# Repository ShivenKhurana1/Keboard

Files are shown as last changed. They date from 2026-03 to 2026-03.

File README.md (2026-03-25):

# Keboard

A custom 60% mechanical keyboard featuring an OLED display and rotary encoder for enhanced functionality. coded using [onshape](https://cad.onshape.com/documents/cca7080cfaf346b1d03e6a45/w/840138e854193d740b07961a/e/62251870f6a2fd42355be13b)

## Features

- **60% Layout**: Compact 60-key layout without function row, navigation cluster, or numpad
- **OLED Display**: 0.91" I2C OLED for displaying status, layers, or custom animations
- **Rotary Encoder**: EC11 rotary encoder for volume control, scrolling, or custom functions
- **Hot-Swap Sockets**: Kailh hot-swap sockets for easy switch swapping without soldering
- **RP2040 Controller**: Powered by Raspberry Pi Pico for excellent performance and QMK compatibility

## Gallery

### CAD Design
CAD Design

### Schematics
Schematics

### PCB Design
PCB

## Bill of Materials

|Item |Qty  |Link |Price |Running total|
|---|-----|---|---|---|
|Keycaps |1 set|[Aliexpress](https://www.aliexpress.us/item/3256809438061445.html?gatewayAdapt=glo2usa4itemAdapt) |13$ |13$ |
|Switches |90pc |[Akko V3 Creamy Purple Pro Switch](https://en.akkogear.com/product/akko-v3-creamy-purple-pro-switch/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) |$30.25|43$ |
|OLED |1 |[0.91 Inch OLED Display](https://www.aliexpress.us/item/3256808609571956.html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) |$5.55 |49$ |
|Raspberry Pi Pico |1 |[Digikey](https://www.digikey.com/en/products/detail/raspberry-pi/SC0917/16608257) |$5.00 |54$ |
|EC11 rotary encoder |1 |[aliexpress](https://www.aliexpress.us/item/3256801690870145.html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) |$2.60 |56$ |
|PCB |1 |JLCPCB |$25.61|82$ |
|Hotswap sockets |70 |[Aliexpress](https://www.aliexpress.us/item/3256807039037559.html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) |$9.54 |92$ |
|Stabilizer Set |1 |[Aliexpress](https://www.aliexpress.us/item/3256801817127792.html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) |$4.25 |96$ |
|Diodes |100  |[aliexpress](https://www.aliexpress.com/ssr/300001493/welcomegiftspmpc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..)|$4.77 |101$ |
|Coupon (3$ off 15$ Aliexpress)| | |-3 |98$ |

**Total Estimated Cost: ~$100**

### PCB Pricing Example
JLCPCB Pricing

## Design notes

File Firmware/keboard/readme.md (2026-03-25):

# keboard

QMK firmware for the keboard RP2040 (Raspberry Pi Pico) keyboard.

## Pins

- Rows: GP14, GP15, GP16, GP17, GP18
- Cols: GP0..GP13
- Encoder: GP27 (A), GP26 (B)
- OLED I2C: GP20 (SDA), GP21 (SCL)

## Notes

- `DIODE_DIRECTION` is set to `COL2ROW`. If your matrix is reversed, flip it in config.h.
- The layout is a generic 5x14 grid. Adjust the keymap to match your physical layout.

## Build

Copy this folder into `qmk_firmware/keyboards/clear60`, then run:

```
qmk compile -kb clear60 -km default
```

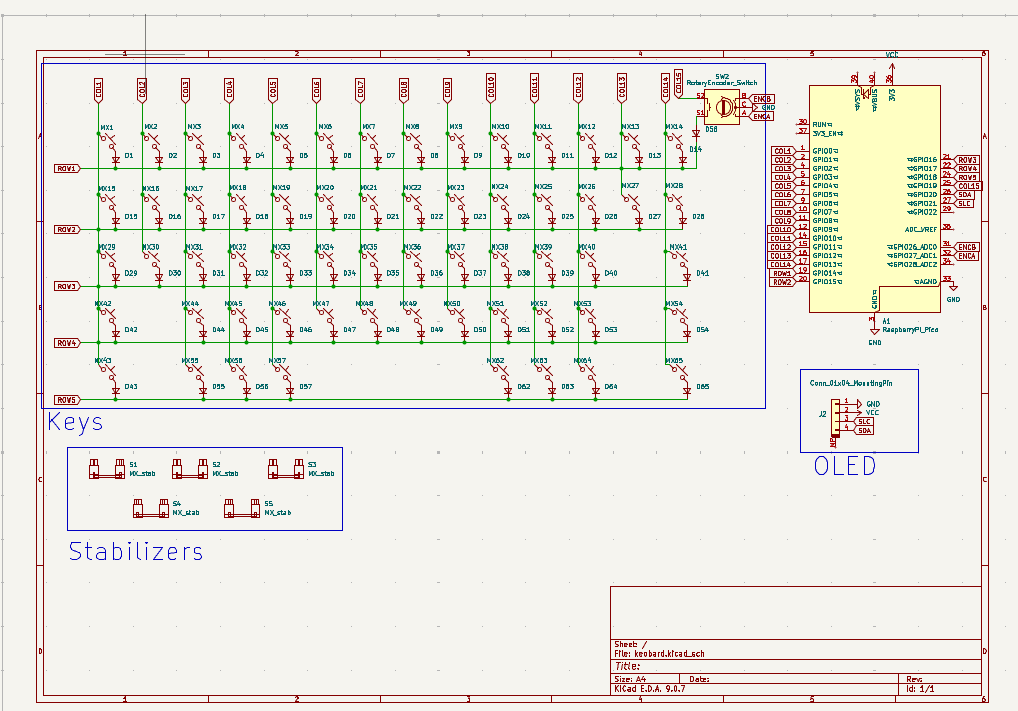
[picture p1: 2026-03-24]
assets/schematics.png

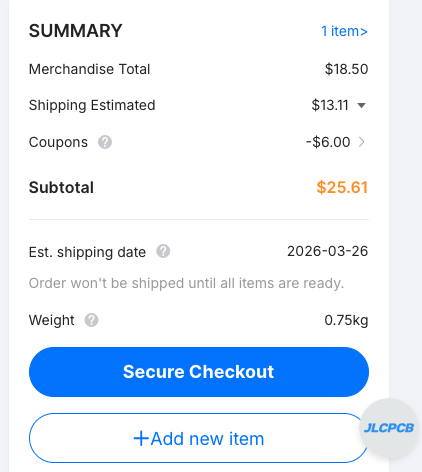
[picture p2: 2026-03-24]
assets/jlcpcb.png

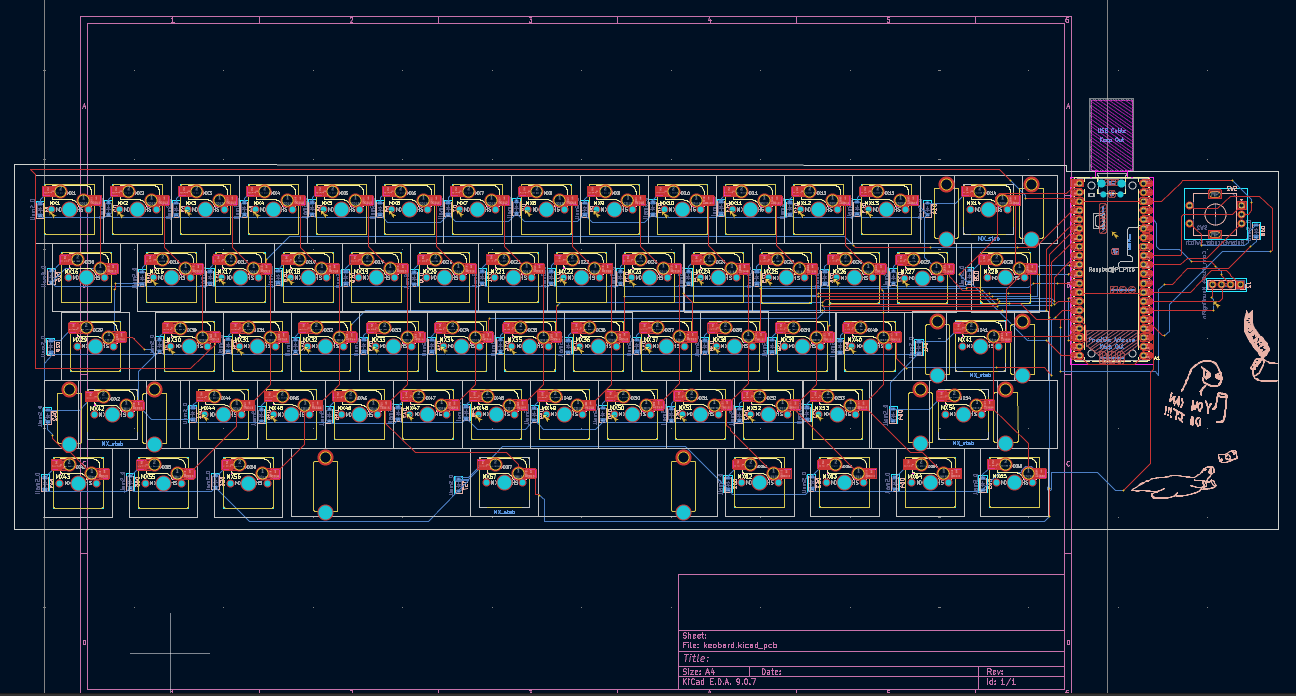
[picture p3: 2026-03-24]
assets/pcb.png

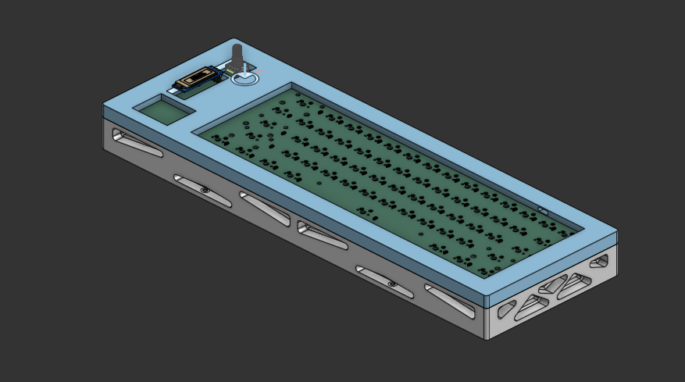
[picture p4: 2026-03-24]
assets/cad.png

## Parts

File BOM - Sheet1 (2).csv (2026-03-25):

Item | Qty | Link | Price | Running total
Keycaps | 1 set | [Aliexpress](https://www.aliexpress.us/item/3256809438061445.html?gatewayAdapt=glo2usa4itemAdapt) | 13$ | 13$
Switches | 90pc | [Akko V3 Creamy Purple Pro Switch](https://en.akkogear.com/product/akko-v3-creamy-purple-pro-switch/?attribute_quantity=45+pcs&wmc-currency=USD | $30.25 | 43$
OLED | 1 | [0.91 Inch OLED Display](https://www.aliexpress.us/item/3256808609571956.html?curPageLogUid=osvBYXtlXRIq | $5.55 | 49$
Raspberry Pi Pico | 1 | [Digikey](https://www.digikey.com/en/products/detail/raspberry-pi/SC0917/16608257) | $5.00 | 54$
EC11 rotary encoder | 1 | [aliexpress](https://www.aliexpress.us/item/3256801690870145.html | $2.60 | 56$
PCB | 1 | JLCPCB | $25.61 | 82$
Hotswap sockets | 70 | [Aliexpress](https://www.aliexpress.us/item/3256807039037559.html?src=google | $9.54 | 92$
Stabilizer Set | 1 | [Aliexpress](https://www.aliexpress.us/item/3256801817127792.html?curPageLogUid=1E7nWo6FwrMm | $4.25 | 96$
Diodes | 100 | [aliexpress](https://www.aliexpress.com/ssr/300001493/welcomegiftspmpc?businessCode=ug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 | $4.77 | 101$
Coupon (3$ off 15$ Aliexpress) |  |  | -3 | 98$

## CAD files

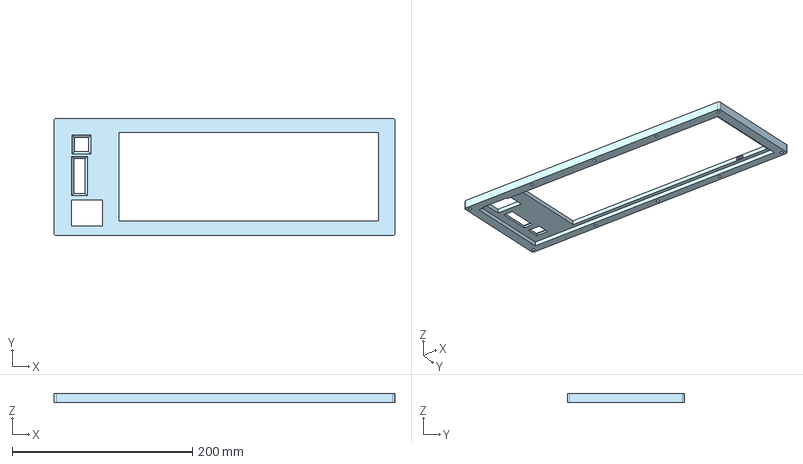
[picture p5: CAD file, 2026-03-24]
CAD/Top Case (2).step
378.7 x 130.5 x 10.2 mm

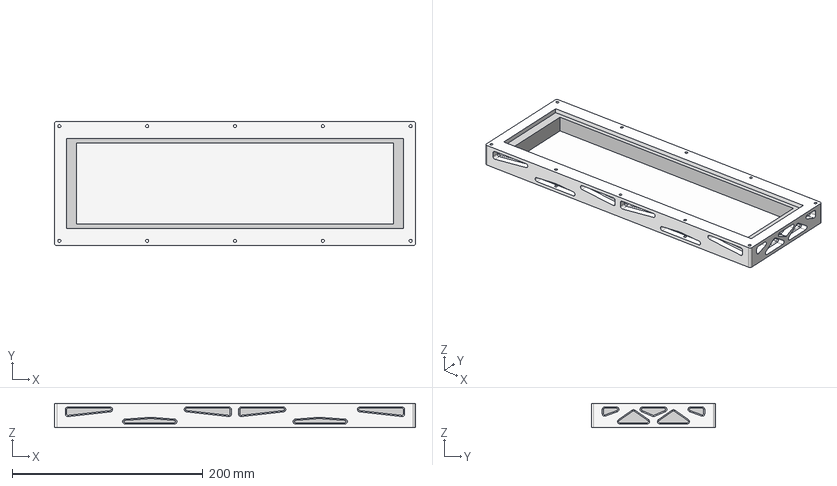
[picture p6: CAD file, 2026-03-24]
CAD/Case.step
378.7 x 130.5 x 25.4 mm

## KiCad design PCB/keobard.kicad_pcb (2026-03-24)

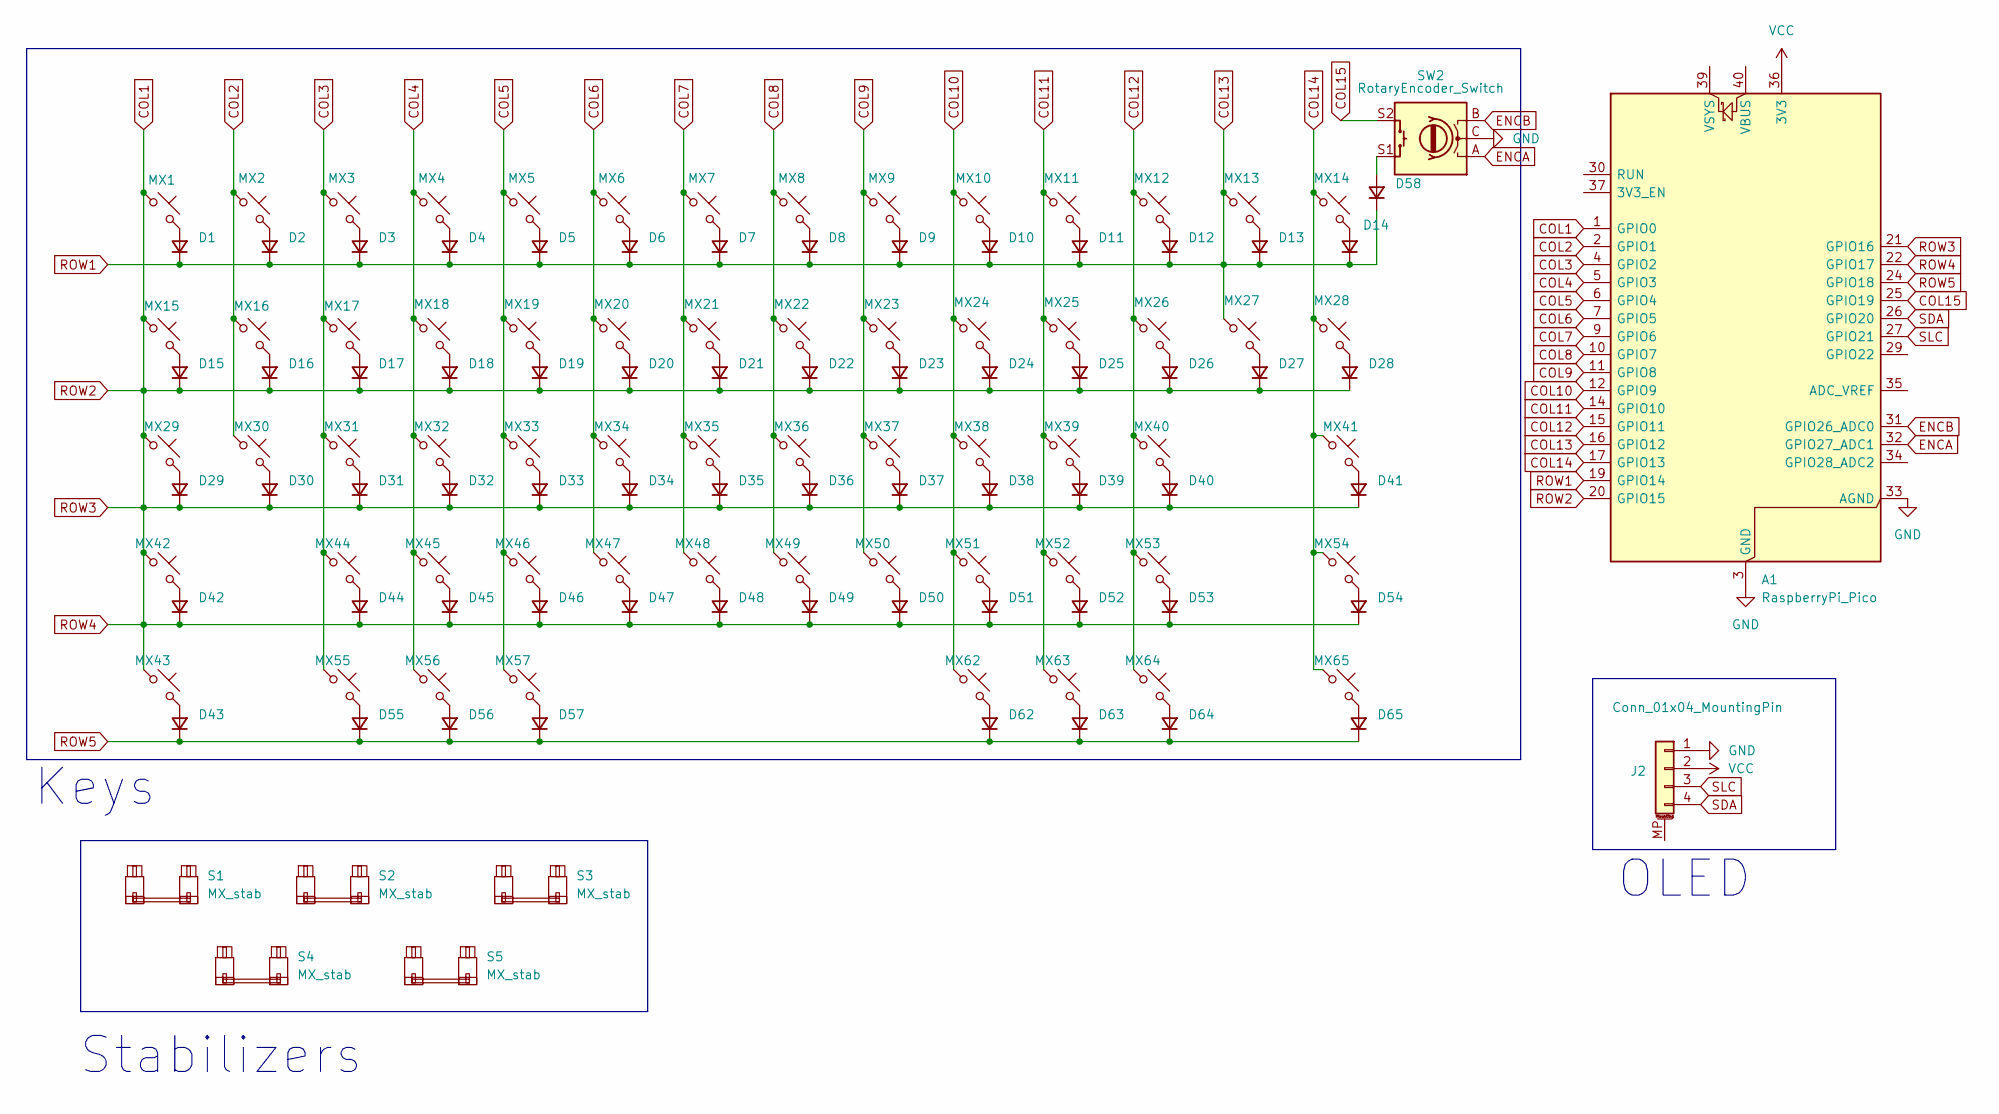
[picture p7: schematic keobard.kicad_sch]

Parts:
A1: RaspberryPi_Pico; RaspberryPi_Pico_Common_Unspecified
D1, D2, D3, D4, D5, D6, D7, D8, D9, D10, D11, D12, D13, D14, D15, D16, D17, D18, D19, D20, D21, D22, D23, D24, D25, D26, D27, D28, D29, D30, D31, D32, D33, D34, D35, D36, D37, D38, D39, D40, D41, D42, D43, D44, D45, D46, D47, D48, D49, D50, D51, D52, D53, D54, D55, D56, D57, D58, D62, D63, D64, D65: D_Small; D_SOD-123
J2: Conn_01x04_MountingPin; PinHeader_1x04_P2.54mm_Vertical
MX1, MX2, MX3, MX4, MX5, MX6, MX7, MX8, MX9, MX10, MX11, MX12, MX13, MX14, MX15, MX16, MX17, MX18, MX19, MX20, MX21, MX22, MX23, MX24, MX25, MX26, MX27, MX28, MX29, MX30, MX31, MX32, MX33, MX34, MX35, MX36, MX37, MX38, MX39, MX40, MX41, MX42, MX43, MX44, MX45, MX46, MX47, MX48, MX49, MX50, MX51, MX52, MX53, MX54, MX55, MX56, MX57, MX62, MX63, MX64, MX65: MX_SW_HS; SW_MX_HS_CPG151101S11_1u
S1, S2, S3: MX_stab; STAB_MX_P_2u
S4: MX_stab; STAB_MX_P_2.75u
S5: MX_stab; STAB_MX_P_6.25u
SW2: RotaryEncoder_Switch; RotaryEncoder_Alps_EC11E-Switch_Vertical_H20mm

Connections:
COL1: A1.1 (GPIO0), A1.20 (GPIO15), A1.21 (GPIO16), A1.22 (GPIO17), D15.1 (K), D16.1 (K), D17.1 (K), D18.1 (K), D19.1 (K), D20.1 (K), D21.1 (K), D22.1 (K), D23.1 (K), D24.1 (K), D25.1 (K), D26.1 (K), D27.1 (K), D28.1 (K), D29.1 (K), D30.1 (K), D31.1 (K), D32.1 (K), D33.1 (K), D34.1 (K), D35.1 (K), D36.1 (K), D37.1 (K), D38.1 (K), D39.1 (K), D40.1 (K), D41.1 (K), D42.1 (K), D44.1 (K), D45.1 (K), D46.1 (K), D47.1 (K), D48.1 (K), D49.1 (K), D50.1 (K), D51.1 (K), D52.1 (K), D53.1 (K), D54.1 (K), MX1.1, MX15.1, MX29.1, MX42.1, MX43.1
COL2: A1.2 (GPIO1), MX2.1, MX16.1, MX30.1
COL3: A1.4 (GPIO2), MX3.1, MX17.1, MX31.1, MX44.1, MX55.1
COL4: A1.5 (GPIO3), MX4.1, MX18.1, MX32.1, MX45.1, MX56.1
COL5: A1.6 (GPIO4), MX5.1, MX19.1, MX33.1, MX46.1, MX57.1
COL6: A1.7 (GPIO5), MX6.1, MX20.1, MX34.1, MX47.1
COL7: A1.9 (GPIO6), MX7.1, MX21.1, MX35.1, MX48.1
COL8: A1.10 (GPIO7), MX8.1, MX22.1, MX36.1, MX49.1
COL9: A1.11 (GPIO8), MX9.1, MX23.1, MX37.1, MX50.1
COL10: A1.12 (GPIO9), MX10.1, MX24.1, MX38.1, MX51.1, MX62.1
COL11: A1.14 (GPIO10), MX11.1, MX25.1, MX39.1, MX52.1, MX63.1
COL12: A1.15 (GPIO11), MX12.1, MX26.1, MX40.1, MX53.1, MX64.1
COL13: A1.16 (GPIO12), A1.19 (GPIO14), D1.1 (K), D2.1 (K), D3.1 (K), D4.1 (K), D5.1 (K), D6.1 (K), D7.1 (K), D8.1 (K), D9.1 (K), D10.1 (K), D11.1 (K), D12.1 (K), D13.1 (K), D14.1 (K), D58.1 (K), MX13.1, MX27.1
COL14: A1.17 (GPIO13), MX14.1, MX28.1, MX41.1, MX54.1, MX65.1
COL15: A1.25 (GPIO19), SW2.S2
ENCA: A1.32 (GPIO27_ADC1), SW2.A
ENCB: A1.31 (GPIO26_ADC0), SW2.B
GND: A1.3 (GND), A1.8 (GND), A1.13 (GND), A1.18 (GND), A1.23 (GND), A1.28 (GND), A1.33 (AGND), A1.38 (GND), J2.1, SW2.C
unnamed: D1.2 (A), MX1.2
unnamed: D2.2 (A), MX2.2
unnamed: D3.2 (A), MX3.2
unnamed: D4.2 (A), MX4.2
unnamed: D5.2 (A), MX5.2
unnamed: D6.2 (A), MX6.2
unnamed: D7.2 (A), MX7.2
unnamed: D8.2 (A), MX8.2
unnamed: D9.2 (A), MX9.2
unnamed: D10.2 (A), MX10.2
unnamed: D11.2 (A), MX11.2
unnamed: D12.2 (A), MX12.2
unnamed: D13.2 (A), MX13.2
unnamed: D14.2 (A), MX14.2
unnamed: D15.2 (A), MX15.2
unnamed: D16.2 (A), MX16.2
unnamed: D17.2 (A), MX17.2
unnamed: D18.2 (A), MX18.2
unnamed: D19.2 (A), MX19.2
unnamed: D20.2 (A), MX20.2
unnamed: D21.2 (A), MX21.2
unnamed: D22.2 (A), MX22.2
unnamed: D23.2 (A), MX23.2
unnamed: D24.2 (A), MX24.2
unnamed: D25.2 (A), MX25.2
unnamed: D26.2 (A), MX26.2
unnamed: D27.2 (A), MX27.2
unnamed: D28.2 (A), MX28.2
unnamed: D29.2 (A), MX29.2
unnamed: D30.2 (A), MX30.2
unnamed: D31.2 (A), MX31.2
unnamed: D32.2 (A), MX32.2
unnamed: D33.2 (A), MX33.2
unnamed: D34.2 (A), MX34.2
unnamed: D35.2 (A), MX35.2
unnamed: D36.2 (A), MX36.2
unnamed: D37.2 (A), MX37.2
unnamed: D38.2 (A), MX38.2
unnamed: D39.2 (A), MX39.2
unnamed: D40.2 (A), MX40.2
unnamed: D41.2 (A), MX41.2
unnamed: D42.2 (A), MX42.2
unnamed: D43.2 (A), MX43.2
unnamed: D44.2 (A), MX44.2
unnamed: D45.2 (A), MX45.2
unnamed: D46.2 (A), MX46.2
unnamed: D47.2 (A), MX47.2
unnamed: D48.2 (A), MX48.2
unnamed: D49.2 (A), MX49.2
unnamed: D50.2 (A), MX50.2
unnamed: D51.2 (A), MX51.2
unnamed: D52.2 (A), MX52.2
unnamed: D53.2 (A), MX53.2
unnamed: D54.2 (A), MX54.2
unnamed: D55.2 (A), MX55.2
unnamed: D56.2 (A), MX56.2
unnamed: D57.2 (A), MX57.2
unnamed: D58.2 (A), SW2.S1
unnamed: D62.2 (A), MX62.2
unnamed: D63.2 (A), MX63.2
unnamed: D64.2 (A), MX64.2
unnamed: D65.2 (A), MX65.2
ROW5: A1.24 (GPIO18), D43.1 (K), D55.1 (K), D56.1 (K), D57.1 (K), D62.1 (K), D63.1 (K), D64.1 (K), D65.1 (K)
SDA: A1.26 (GPIO20), J2.4
SLC: A1.27 (GPIO21), J2.3
VCC: A1.36 (3V3), J2.2

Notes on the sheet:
Keys
OLED
Stabilizers

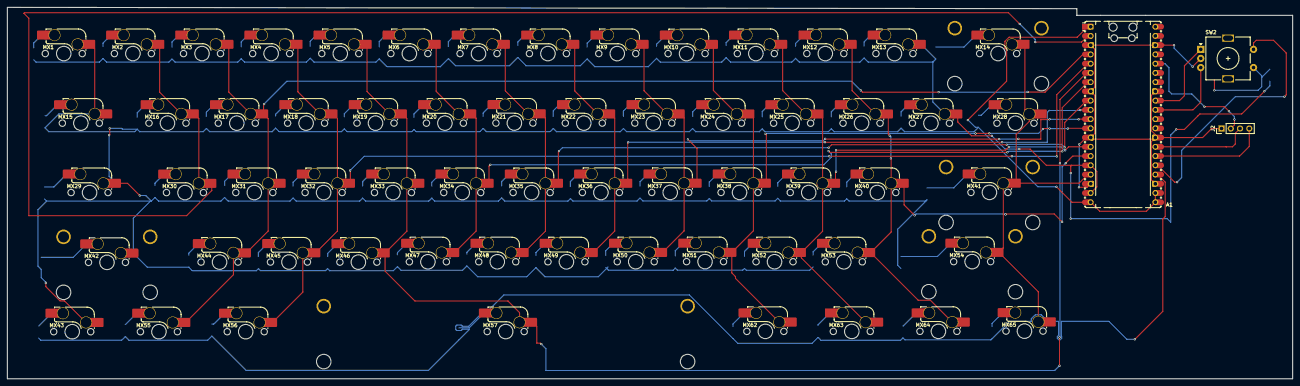
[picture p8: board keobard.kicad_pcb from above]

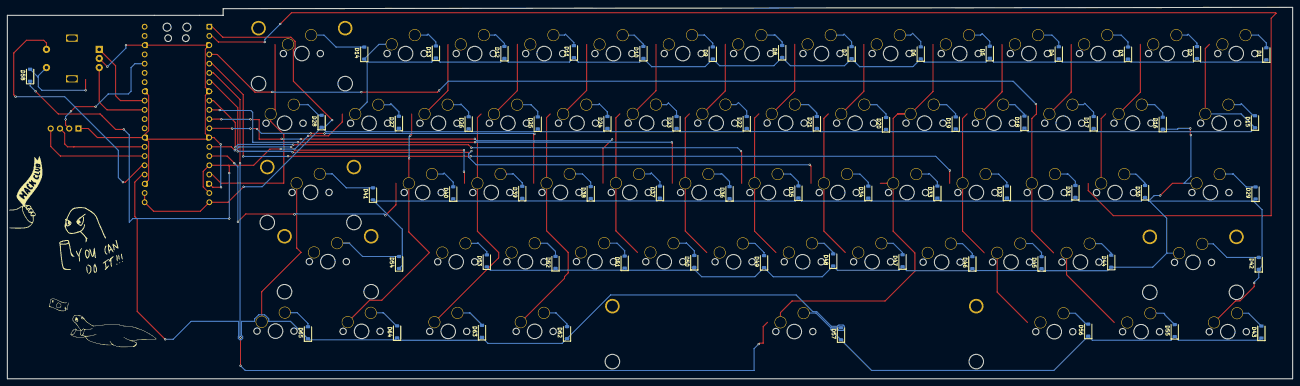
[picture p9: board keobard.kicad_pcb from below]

Board: 2 copper layers, 353.3 x 102.1 mm, 133 parts (64 on the bottom side), 84 nets.

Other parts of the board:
"": LOGO
""#2: LOGO

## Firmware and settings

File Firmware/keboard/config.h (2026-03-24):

#pragma once

#define MATRIX_ROWS 5
#define MATRIX_COLS 14

#define MATRIX_ROW_PINS { GP14, GP15, GP16, GP17, GP18 }
#define MATRIX_COL_PINS { GP0, GP1, GP2, GP3, GP4, GP5, GP6, GP7, GP8, GP9, GP10, GP11, GP12, GP13 }

#define DIODE_DIRECTION COL2ROW

#define ENCODER_A_PINS { GP27 }
#define ENCODER_B_PINS { GP26 }
#define ENCODER_RESOLUTION 4

#define I2C0_SDA_PIN GP20
#define I2C0_SCL_PIN GP21

#define OLED_DISPLAY_128X32
#define OLED_BRIGHTNESS 128

#define DEBOUNCE 5

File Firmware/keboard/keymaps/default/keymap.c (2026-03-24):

#include QMK_KEYBOARD_H

enum layers {
    _BASE,
    _FN
};

const uint16_t PROGMEM keymaps[][MATRIX_ROWS][MATRIX_COLS] = {
    [_BASE] = LAYOUT(
        KC_ESC,  KC_1,    KC_2,    KC_3,    KC_4,    KC_5,    KC_6,    KC_7,    KC_8,    KC_9,    KC_0,    KC_MINS, KC_EQL,  KC_BSPC,
        KC_TAB,  KC_Q,    KC_W,    KC_E,    KC_R,    KC_T,    KC_Y,    KC_U,    KC_I,    KC_O,    KC_P,    KC_LBRC, KC_RBRC, KC_BSLS,
        KC_CAPS, KC_A,    KC_S,    KC_D,    KC_F,    KC_G,    KC_H,    KC_J,    KC_K,    KC_L,    KC_SCLN, KC_QUOT, KC_ENT,  KC_PGUP,
        KC_LSFT, KC_Z,    KC_X,    KC_C,    KC_V,    KC_B,    KC_N,    KC_M,    KC_COMM, KC_DOT,  KC_SLSH, KC_RSFT, KC_UP,   KC_DEL,
        KC_LCTL, KC_LGUI, KC_LALT, KC_SPC,  KC_SPC,  KC_SPC,  KC_RALT, KC_RGUI, KC_MENU, KC_RCTL, KC_LEFT, KC_DOWN, KC_RGHT, MO(_FN)
    ),
    [_FN] = LAYOUT(
        KC_GRV,  KC_F1,   KC_F2,   KC_F3,   KC_F4,   KC_F5,   KC_F6,   KC_F7,   KC_F8,   KC_F9,   KC_F10,  KC_F11,  KC_F12,  KC_DEL,
        KC_TRNS, KC_TRNS, KC_TRNS, KC_TRNS, KC_TRNS, KC_TRNS, KC_TRNS, KC_TRNS, KC_TRNS, KC_TRNS, KC_TRNS, KC_TRNS, KC_TRNS, KC_TRNS,
        KC_TRNS, KC_TRNS, KC_TRNS, KC_TRNS, KC_TRNS, KC_TRNS, KC_TRNS, KC_TRNS, KC_TRNS, KC_TRNS, KC_TRNS, KC_TRNS, KC_TRNS, KC_TRNS,
        KC_TRNS, KC_TRNS, KC_TRNS, KC_TRNS, KC_TRNS, KC_TRNS, KC_TRNS, KC_TRNS, KC_TRNS, KC_TRNS, KC_TRNS, KC_TRNS, KC_TRNS, KC_TRNS,
        KC_TRNS, KC_TRNS, KC_TRNS, KC_TRNS, KC_TRNS, KC_TRNS, KC_TRNS, KC_TRNS, KC_TRNS, KC_TRNS, KC_TRNS, KC_TRNS, KC_TRNS, QK_BOOT
    )
};

#ifdef ENCODER_MAP_ENABLE
const uint16_t PROGMEM encoder_map[][NUM_ENCODERS][2] = {
    [_BASE] = { ENCODER_CCW_CW(KC_VOLD, KC_VOLU) },
    [_FN]   = { ENCODER_CCW_CW(KC_PGDN, KC_PGUP) }
};
#endif

#ifdef OLED_ENABLE
static void render_layer_state(void) {
    oled_write_ln_P(PSTR("Clear60"), false);
    oled_write_P(PSTR("Layer: "), false);
    switch (get_highest_layer(layer_state)) {
        case _FN:
            oled_write_ln_P(PSTR("FN"), false);
            break;
        default:
            oled_write_ln_P(PSTR("Base"), false);
            break;
    }
}

bool oled_task_user(void) {
    oled_clear();
    render_layer_state();
    oled_write_P(PSTR("Caps: "), false);
    oled_write_ln_P(host_keyboard_led_state().caps_lock ? PSTR("ON") : PSTR("OFF"), false);
    return false;
}
#endif

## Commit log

2026-03-24 Add initial README with CAD, Schematics, and PCB images
2026-03-24 Add BOM section to README
    Added a Bill of Materials (BOM) section with item details, quantities, links, prices, and running totals.
2026-03-24 Add schematics section with image
2026-03-25 Create BOM - Sheet1.csv
    [BOM - Sheet1.csv]
2026-03-25 Revise README for Keboard project details
    Updated the README to provide a detailed overview of the Keboard project, including features, gallery, and bill of materials.
2026-03-25 Refactor Bill of Materials table and update costs
    Updated the Bill of Materials table format and adjusted prices.
